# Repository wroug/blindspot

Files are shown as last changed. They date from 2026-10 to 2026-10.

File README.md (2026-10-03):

blindspotsd  

pcbwide

## What it is
BLINDSPOT is a custom project made for logging keys. It is designed to be as easy to use as possible.  It is made so one can log what's going on between their computer and keyboard, mouse or other peripherals.  
The intended purpose is to use it for either seeing whether your own computer has been used in your absence, or security testing a team on whether they identify and take action against unknown USB devices.  
> The use of it for surveilling others or gathering data without their consent is not endorsed.  

## How to assemble 
 
 1. Solder each component to it's respective pads (reference the BOM)
    assemblyguide

 2. Put the pcb in the bottom half of the case.  
    

3. Screw it to the case using 2x M2x4mm screws at these points.  
    

4. Cover it with the top half of the case, making sure the extrusions insert nicely into the slots.  
    

5. Secure the assembly together with a M2x8mm screw at the bottom  
   

**!! FLASHING INSTRUCTIONS NOT INCLUDED AS THE FIRMWARE IS NOT FINISHED.**

## Software

[ WIP ]

## Pictures




## Bom
|Reference|Qty| Value | Size | 
|--|--|--|--|
|C1, C2, C11, C15, C16, C17, C18, C19, C20, C21, C22, C23, C24|13|100nF|0603
|C3, C4, C5, C6, C12, C25, C26|7|1uF|0603
|C7, C8, C9, C10|4|27pF|0603
|C27|1|10uF|0805
|D1|1|Orange LED|0603
|D2|1|Blue LED|0603
|J2|1|480370001|-
|J3|1|292303-5|-
|R1, R2|2|33R|0603
|R3, R4|2|27R|0603
|R5, R6|2|10k|0603
|U1|1|RP2040|QFN-56_7X7
|U2|1|W25Q32JVSS|SOIC-8
|U3|1|AP2112K-3.3|SOT-23-5
|U4, U6|2|USBLC6-2SC6|SOT-23-6
|U5|1|MAX3421EETJ_|32-WFQFN-EP
|Y1, Y2|2|12MHz|5032-2

### Notes:
> The W25Q32JVSS (U2) can be substituted with any SOIC-8 flash memory chip of the same lineup (W25Q__JV) with a maximum of 128MiB space usable.

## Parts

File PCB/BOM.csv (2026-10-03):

Reference | Qty | Value | DNP | Exclude from BOM | Exclude from Board | Footprint | Datasheet
C1,C2,C11,C15,C16,C17,C18,C19,C20,C21,C22,C23,C24 | 13 | 100nF |  |  |  | Capacitor_SMD:C_0603_1608Metric_Pad1.08x0.95mm_HandSolder | ~
C3,C4,C5,C6,C12,C25,C26 | 7 | 1uF |  |  |  | Capacitor_SMD:C_0603_1608Metric_Pad1.08x0.95mm_HandSolder | ~
C7,C8,C9,C10 | 4 | 27pF |  |  |  | Capacitor_SMD:C_0603_1608Metric_Pad1.08x0.95mm_HandSolder | ~
C27 | 1 | 10uF |  |  |  | Capacitor_SMD:C_0805_2012Metric_Pad1.18x1.45mm_HandSolder | ~
D1 | 1 | LED_BLUE |  |  |  | LED_SMD:LED_0603_1608Metric_Pad1.05x0.95mm_HandSolder | ~
D2 | 1 | LED_ORANGE |  |  |  | LED_SMD:LED_0603_1608Metric_Pad1.05x0.95mm_HandSolder | ~
J2 | 1 | USB_A_MALE |  |  |  | 480370001:CONN_480370001_MOL | ~
J3 | 1 | USB_A_FEMALE |  |  |  | 292303-5:CONN4_292303_TEC | ~
R1,R2 | 2 | 33R |  |  |  | Resistor_SMD:R_0603_1608Metric_Pad0.98x0.95mm_HandSolder | ~
R3,R4 | 2 | 27R |  |  |  | Resistor_SMD:R_0603_1608Metric_Pad0.98x0.95mm_HandSolder | ~
R5,R6 | 2 | 10k |  |  |  | Resistor_SMD:R_0603_1608Metric_Pad0.98x0.95mm_HandSolder | ~
TP1,TP2 | 2 | TestPoint |  |  |  |  | ~
U1 | 1 | RP2040 |  |  |  | Package_DFN_QFN:QFN-56-1EP_7x7mm_P0.4mm_EP3.2x3.2mm | https://datasheets.raspberrypi.com/rp2040/rp2040-datasheet.pdf
U2 | 1 | W25Q32JVSS |  |  |  | Package_SO:SOIC-8_5.3x5.3mm_P1.27mm | http://www.winbond.com/resource-files/w25q32jv%20revg%2003272018%20plus.pdf
U3 | 1 | AP2112K-3.3 |  |  |  | Package_TO_SOT_SMD:SOT-23-5 | https://www.diodes.com/assets/Datasheets/AP2112.pdf
U4,U6 | 2 | USBLC6-2SC6 |  |  |  | Package_TO_SOT_SMD:SOT-23-6 | https://www.st.com/resource/en/datasheet/usblc6-2.pdf
U5 | 1 | MAX3421EETJ_ |  |  |  | MAX3421EETJ:21-0140L_T3255-4_MXM
Y1,Y2 | 2 | 12MHz |  |  |  | Crystal:Crystal_SMD_5032-2Pin_5.0x3.2mm_HandSoldering | ~

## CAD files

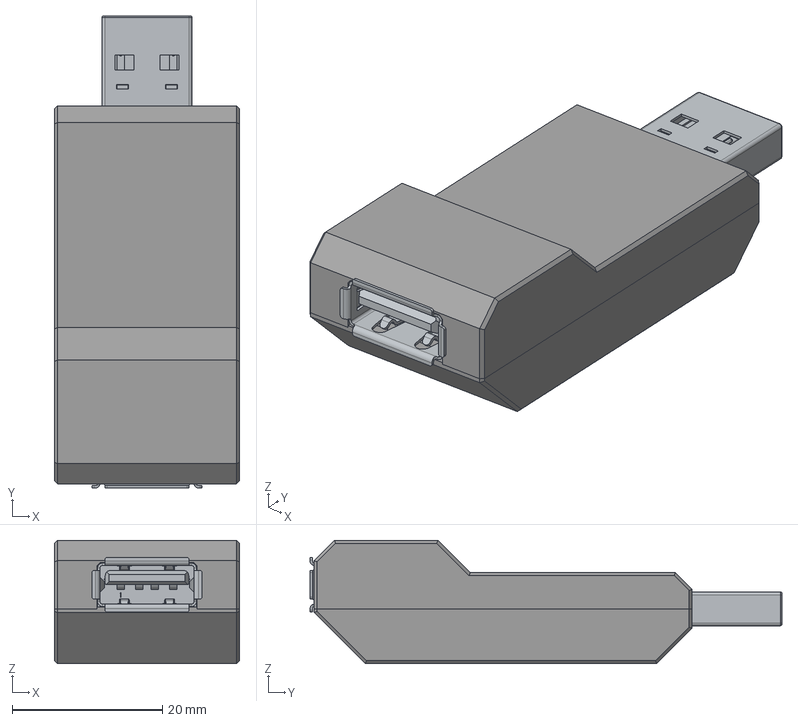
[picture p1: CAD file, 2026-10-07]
CAD/pcb-enclosure.step
24.6 x 62.7 x 16.4 mm
Bottom
Top
C_0603_1608Metric
21-0140L_T3255-4_MXM
21-0140L_T3255-4_MXM001
21-0140L_T3255-4_MXM002
21-0140L_T3255-4_MXM003
21-0140L_T3255-4_MXM004
21-0140L_T3255-4_MXM005
21-0140L_T3255-4_MXM006
21-0140L_T3255-4_MXM007
21-0140L_T3255-4_MXM008
21-0140L_T3255-4_MXM009
21-0140L_T3255-4_MXM010
21-0140L_T3255-4_MXM011
21-0140L_T3255-4_MXM012
21-0140L_T3255-4_MXM013
21-0140L_T3255-4_MXM014
21-0140L_T3255-4_MXM015
21-0140L_T3255-4_MXM016
21-0140L_T3255-4_MXM017
21-0140L_T3255-4_MXM018
21-0140L_T3255-4_MXM019
21-0140L_T3255-4_MXM020
21-0140L_T3255-4_MXM021
21-0140L_T3255-4_MXM022
21-0140L_T3255-4_MXM023
21-0140L_T3255-4_MXM024
21-0140L_T3255-4_MXM025
21-0140L_T3255-4_MXM026
21-0140L_T3255-4_MXM027
21-0140L_T3255-4_MXM028
21-0140L_T3255-4_MXM029
21-0140L_T3255-4_MXM030
21-0140L_T3255-4_MXM031
21-0140L_T3255-4_MXM032
21-0140L_T3255-4_MXM033
21-0140L_T3255-4_MXM034
LED_0603_1608Metric
LED_0603_1608Metric001
Crystal_SMD_5032-2Pin_5.0x3.2mm
c-292303-5-f-3d
SOT-23-5
C_0603_1608Metric001
C_0603_1608Metric002
C_0603_1608Metric003
C_0603_1608Metric004
C_0603_1608Metric005
QFN-56-1EP_7x7mm_P0.4mm_EP3.2x3.2mm
C_0603_1608Metric006
C_0603_1608Metric007
C_0603_1608Metric008
C_0603_1608Metric009
C_0603_1608Metric010
C_0603_1608Metric011
C_0603_1608Metric012
Crystal_SMD_5032-2Pin_5.0x3.2mm001
C_0603_1608Metric013
C_0603_1608Metric014
SOT-23-6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

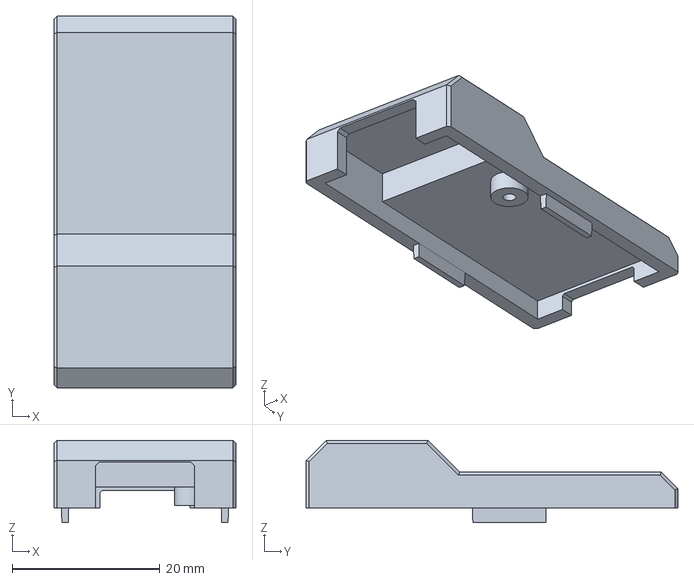
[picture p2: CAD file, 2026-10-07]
CAD/pcb-enclosure-Top.step
24.6 x 50.2 x 11.1 mm

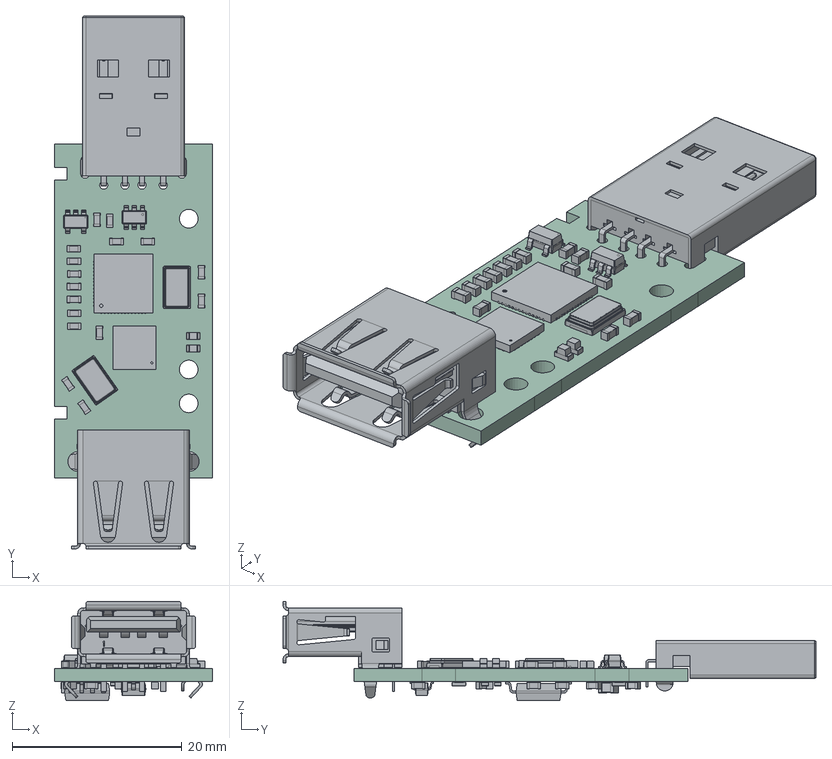
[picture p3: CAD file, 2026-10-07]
CAD/pcb.step
18.6 x 62.7 x 11.7 mm
C_0603_1608Metric
21-0140L_T3255-4_MXM
21-0140L_T3255-4_MXM001
21-0140L_T3255-4_MXM002
21-0140L_T3255-4_MXM003
21-0140L_T3255-4_MXM004
21-0140L_T3255-4_MXM005
21-0140L_T3255-4_MXM006
21-0140L_T3255-4_MXM007
21-0140L_T3255-4_MXM008
21-0140L_T3255-4_MXM009
21-0140L_T3255-4_MXM010
21-0140L_T3255-4_MXM011
21-0140L_T3255-4_MXM012
21-0140L_T3255-4_MXM013
21-0140L_T3255-4_MXM014
21-0140L_T3255-4_MXM015
21-0140L_T3255-4_MXM016
21-0140L_T3255-4_MXM017
21-0140L_T3255-4_MXM018
21-0140L_T3255-4_MXM019
21-0140L_T3255-4_MXM020
21-0140L_T3255-4_MXM021
21-0140L_T3255-4_MXM022
21-0140L_T3255-4_MXM023
21-0140L_T3255-4_MXM024
21-0140L_T3255-4_MXM025
21-0140L_T3255-4_MXM026
21-0140L_T3255-4_MXM027
21-0140L_T3255-4_MXM028
21-0140L_T3255-4_MXM029
21-0140L_T3255-4_MXM030
21-0140L_T3255-4_MXM031
21-0140L_T3255-4_MXM032
21-0140L_T3255-4_MXM033
21-0140L_T3255-4_MXM034
LED_0603_1608Metric
LED_0603_1608Metric001
Crystal_SMD_5032-2Pin_5.0x3.2mm
c-292303-5-f-3d
SOT-23-5
C_0603_1608Metric001
C_0603_1608Metric002
C_0603_1608Metric003
C_0603_1608Metric004
C_0603_1608Metric005
QFN-56-1EP_7x7mm_P0.4mm_EP3.2x3.2mm
C_0603_1608Metric006
C_0603_1608Metric007
C_0603_1608Metric008
C_0603_1608Metric009
C_0603_1608Metric010
C_0603_1608Metric011
C_0603_1608Metric012
Crystal_SMD_5032-2Pin_5.0x3.2mm001
C_0603_1608Metric013
C_0603_1608Metric014
SOT-23-6
C_0603_1608Metric015
R_0603_1608Metric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

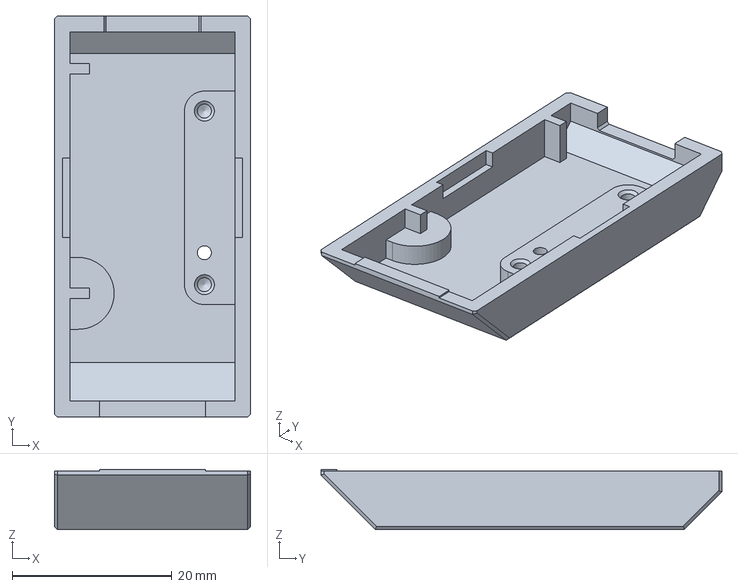
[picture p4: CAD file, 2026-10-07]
CAD/pcb-enclosure-Bottom.step
24.6 x 50.2 x 7.52 mm

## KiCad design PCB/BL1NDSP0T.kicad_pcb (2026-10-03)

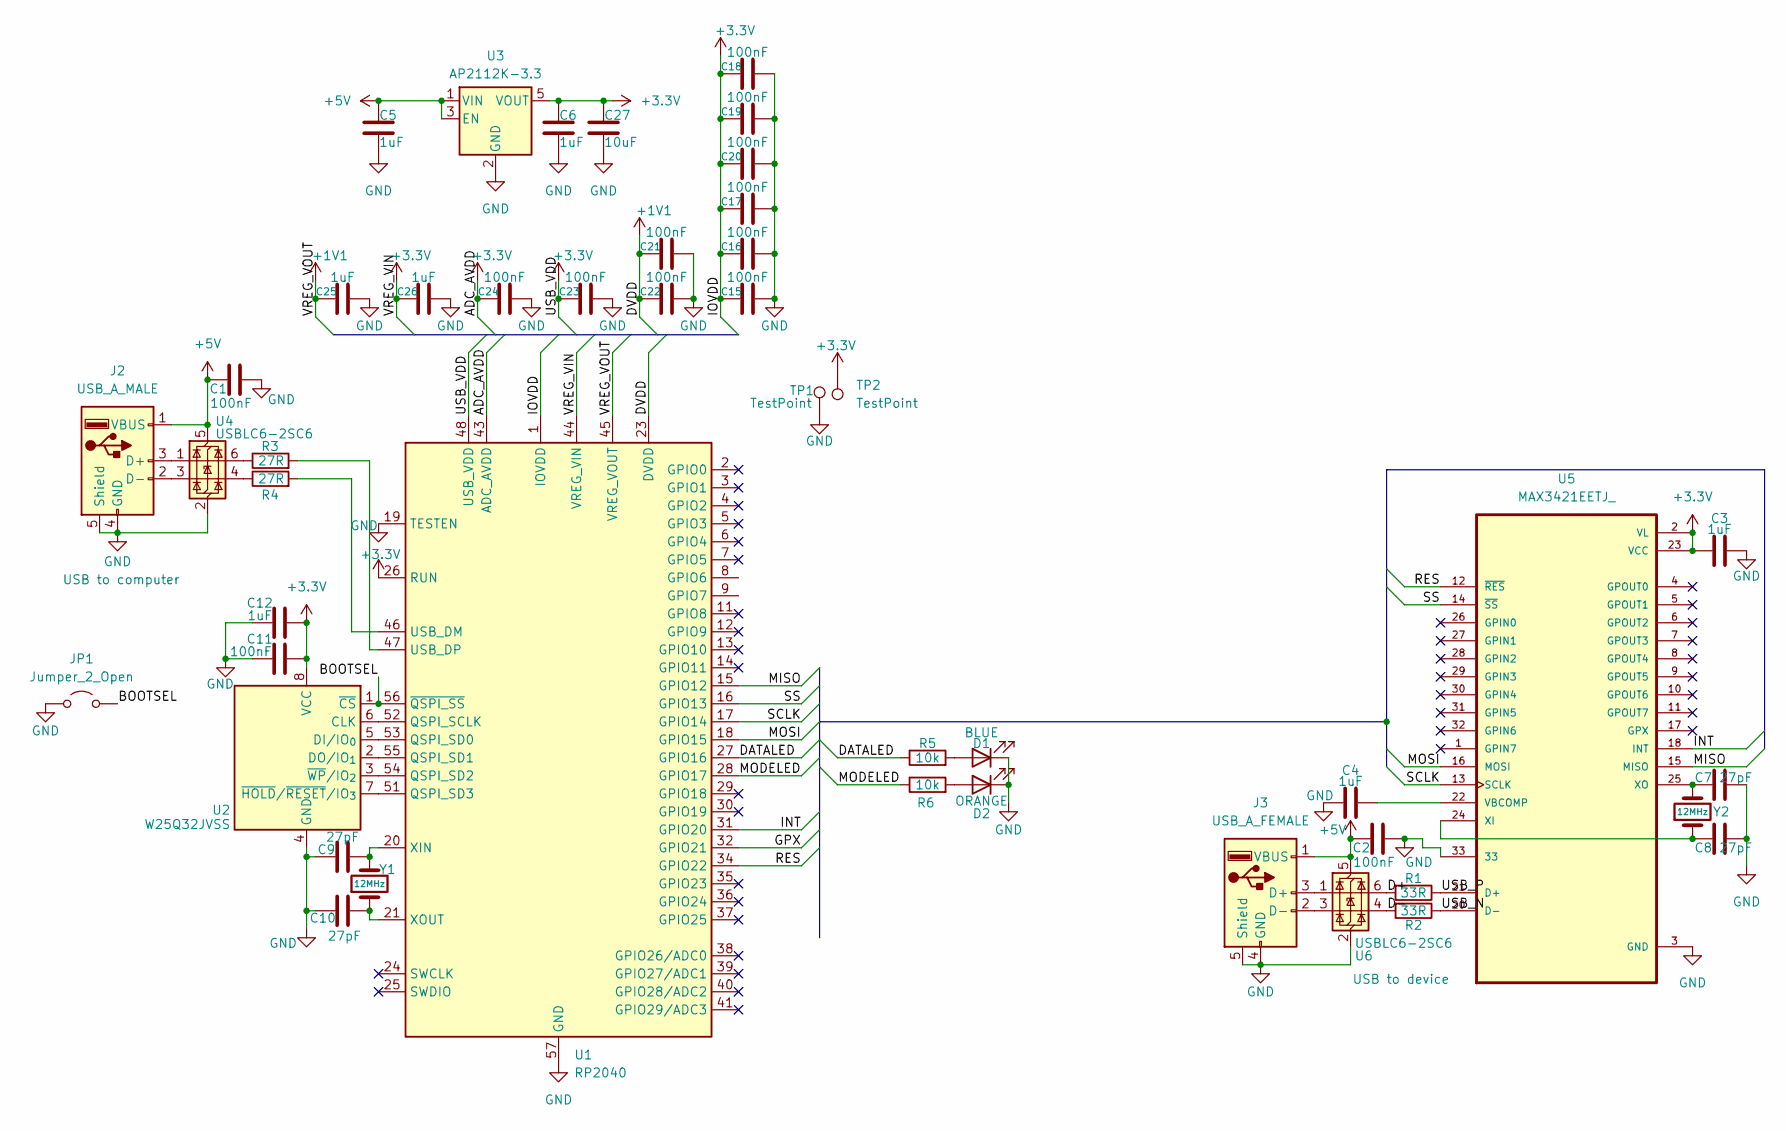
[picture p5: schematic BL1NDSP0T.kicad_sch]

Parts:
C1, C2, C11, C15, C16, C17, C18, C19, C20, C21, C22, C23, C24: 100nF; C_0603_1608Metric_Pad1.08x0.95mm_HandSolder
C3, C4, C5, C6, C12, C25, C26: 1uF; C_0603_1608Metric_Pad1.08x0.95mm_HandSolder
C7, C8, C9, C10: 27pF; C_0603_1608Metric_Pad1.08x0.95mm_HandSolder
C27: 10uF; C_0805_2012Metric_Pad1.18x1.45mm_HandSolder
D1: BLUE; LED_0603_1608Metric_Pad1.05x0.95mm_HandSolder
D2: ORANGE; LED_0603_1608Metric_Pad1.05x0.95mm_HandSolder
J2: USB_A_MALE; CONN_480370001_MOL
J3: USB_A_FEMALE; CONN4_292303_TEC
JP1: Jumper_2_Open; SolderJumper-2_P1.3mm_Open_Pad1.0x1.5mm
R1, R2: 33R; R_0603_1608Metric_Pad0.98x0.95mm_HandSolder
R3, R4: 27R; R_0603_1608Metric_Pad0.98x0.95mm_HandSolder
R5, R6: 10k; R_0603_1608Metric_Pad0.98x0.95mm_HandSolder
TP1, TP2: TestPoint
U1: RP2040; QFN-56-1EP_7x7mm_P0.4mm_EP3.2x3.2mm
U2: W25Q32JVSS; SOIC-8_5.3x5.3mm_P1.27mm
U3: AP2112K-3.3; SOT-23-5
U4, U6: USBLC6-2SC6; SOT-23-6
U5: MAX3421EETJ_; 21-0140L_T3255-4_MXM
Y1, Y2: 12MHz; Crystal_SMD_5032-2Pin_5.0x3.2mm_HandSoldering

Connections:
+1V1: C21.1, C22.1, C25.1, U1.23 (DVDD), U1.45 (VREG_VOUT), U1.50 (DVDD)
+3.3V: C3.1, C6.1, C11.2, C12.2, C15.1, C16.1, C17.1, C18.1, C19.1, C20.1, C23.1, C24.1, C26.1, C27.1, TP2.1, U1.1 (IOVDD), U1.10 (IOVDD), U1.22 (IOVDD), U1.26 (RUN), U1.33 (IOVDD), U1.42 (IOVDD), U1.43 (ADC_AVDD), U1.44 (VREG_VIN), U1.48 (USB_VDD), U1.49 (IOVDD), U2.8 (VCC), U3.5 (VOUT), U5.2 (VL), U5.23 (VCC)
+5V: C1.1, C2.1, C5.1, J2.1 (VBUS), J3.1 (VBUS), U3.1 (VIN), U3.3 (EN), U4.5 (VBUS), U6.5 (VBUS)
/BOOTSEL: JP1.2 (B), U1.56 (~QSPI_SS), U2.1 (~CS)
/D+: R1.2, U6.6 (I/O1)
/D-: R2.2, U6.4 (I/O2)
/DATALED: R5.1, U1.27 (GPIO16)
/GPX: U1.32 (GPIO21)
/INT: U1.31 (GPIO20), U5.18 (INT)
/MISO: U1.15 (GPIO12), U5.15 (MISO)
/MODELED: R6.1, U1.28 (GPIO17)
/MOSI: U1.18 (GPIO15), U5.16 (MOSI)
/RES: U1.34 (GPIO22), U5.12 (~RES)
/SCLK: U1.17 (GPIO14), U5.13 (SCLK)
/SS: U1.16 (GPIO13), U5.14 (~SS)
/USB_N: R2.1, U5.20 (D-)
/USB_P: R1.1, U5.21 (D+)
GND: C1.2, C2.2, C3.2, C4.1, C5.2, C6.2, C7.2, C8.2, C9.1, C10.1, C11.1, C12.1, C15.2, C16.2, C17.2, C18.2, C19.2, C20.2, C21.2, C22.2, C23.2, C24.2, C25.2, C26.2, C27.2, D1.1 (K), D2.1 (K), J2.4 (GND), J2.5 (Shield), J3.4 (GND), J3.5 (Shield), JP1.1 (A), TP1.1, U1.19 (TESTEN), U1.57 (GND), U2.4 (GND), U3.2 (GND), U4.2 (GND), U5.3 (GND), U5.19 (GND), U5.33, U6.2 (GND)
unnamed: D1.2 (A), R5.2
unnamed: D2.2 (A), R6.2
unnamed: J2.3 (D+), U4.1 (I/O1)
unnamed: J2.2 (D-), U4.3 (I/O2)
unnamed: J3.3 (D+), U6.1 (I/O1)
unnamed: J3.2 (D-), U6.3 (I/O2)
unnamed: R3.1, U4.6 (I/O1)
unnamed: R4.1, U4.4 (I/O2)
unnamed: U1.52 (QSPI_SCLK), U2.6 (CLK)
unnamed: U1.53 (QSPI_SD0), U2.5 (DI/IO_{0})
unnamed: U1.55 (QSPI_SD1), U2.2 (DO/IO_{1})
unnamed: U1.54 (QSPI_SD2), U2.3 (~WP/IO_{2})
unnamed: U1.51 (QSPI_SD3), U2.7 (~HOLD/~RESET/IO_{3})
unnamed: R4.2, U1.46 (USB_DM)
unnamed: R3.2, U1.47 (USB_DP)
unnamed: C9.2, U1.20 (XIN), Y1.2
unnamed: C10.2, U1.21 (XOUT), Y1.1
unnamed: C4.2, U5.22 (VBCOMP)
unnamed: C8.1, U5.24 (XI), Y2.1
unnamed: C7.1, U5.25 (XO), Y2.2

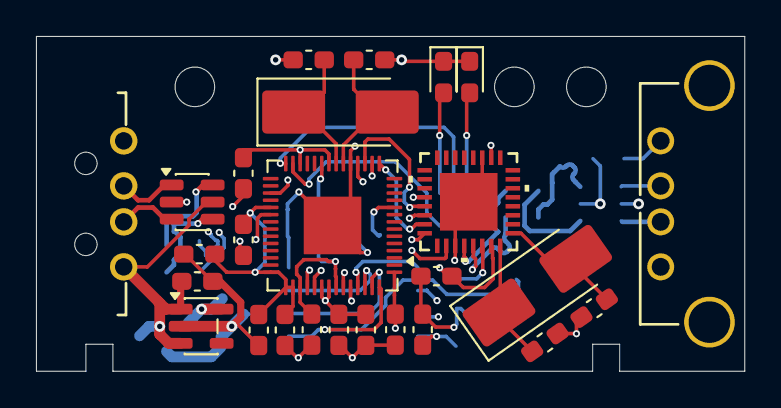
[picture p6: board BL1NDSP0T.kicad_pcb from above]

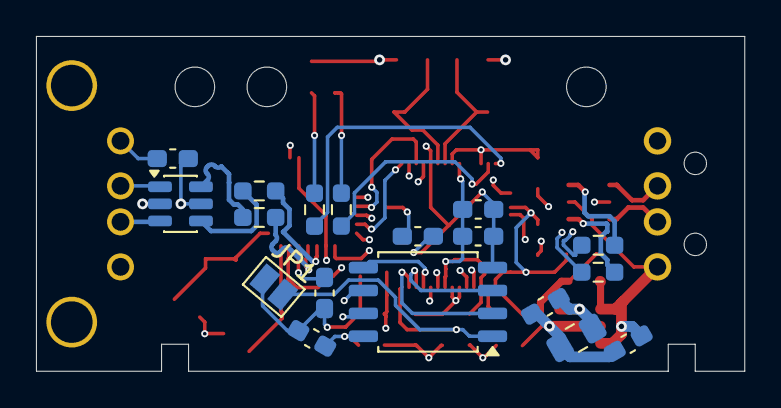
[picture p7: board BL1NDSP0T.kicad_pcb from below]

Board: 4 copper layers, 39.3 x 18.6 mm, 44 parts (18 on the bottom side), 37 nets.

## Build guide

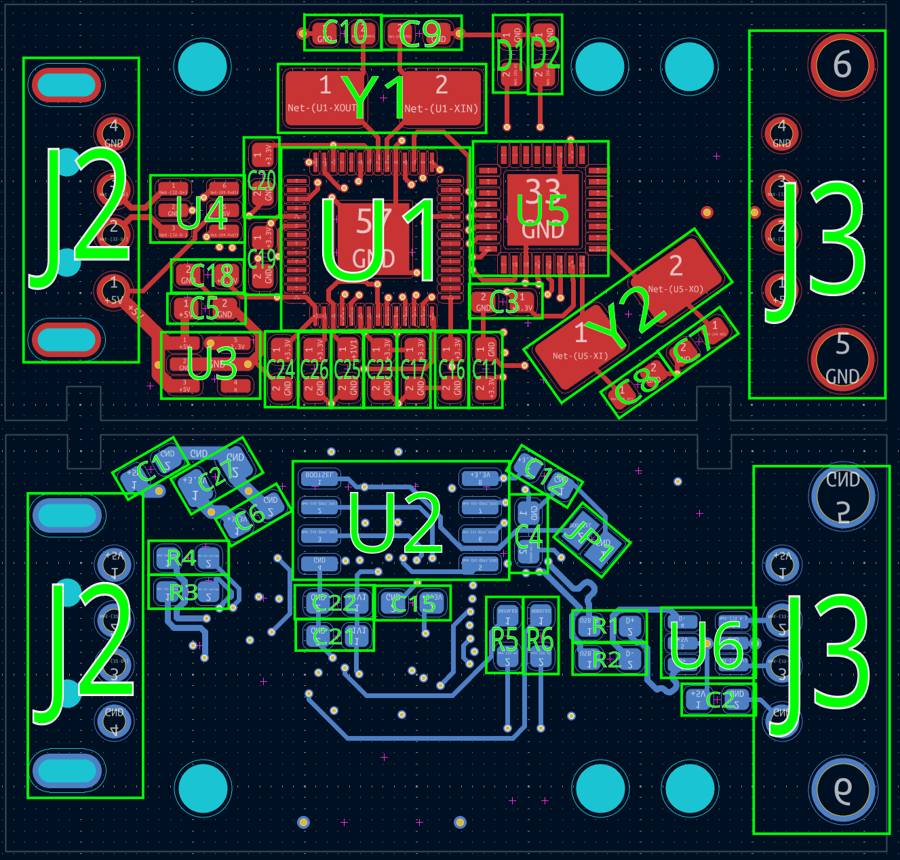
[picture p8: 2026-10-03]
assemblyguide.png

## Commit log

2026-10-03 Enhance README with detailed project information
    Expanded README with assembly instructions, software status, and BOM details.
2026-10-03 Added stp
    [enclosure.stp]
2026-10-07 Orgaized files
    [BL1NDSP0T.kicad_pcb, BL1NDSP0T.kicad_sch, BOM.csv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]
